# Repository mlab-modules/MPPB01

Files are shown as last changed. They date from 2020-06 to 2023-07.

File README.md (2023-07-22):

# MPPB01A -  Mechanical Parallella peripheral board

Elecromechanical interface to [Parallella board](https://parallella.org/). The module is especially useful for connection of [multi-channel](https://github.com/mlab-modules/ADCoctoSPI01) or [high-speed ADCs](https://www.mlab.cz/module/ADCdual01A). 

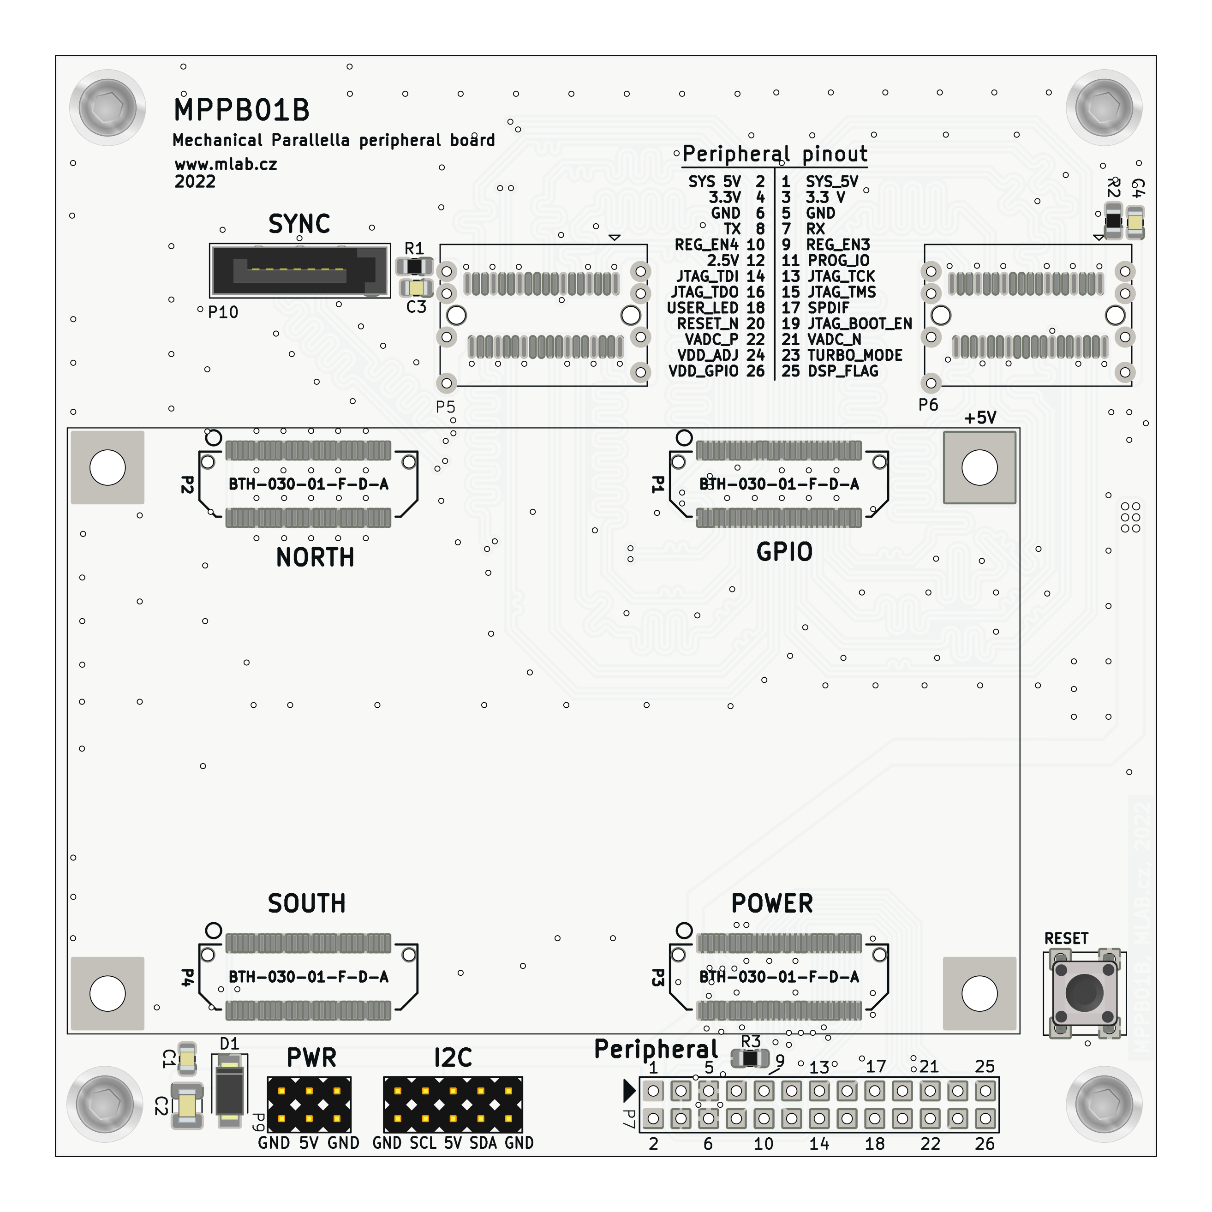
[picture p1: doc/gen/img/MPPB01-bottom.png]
MPPB01B

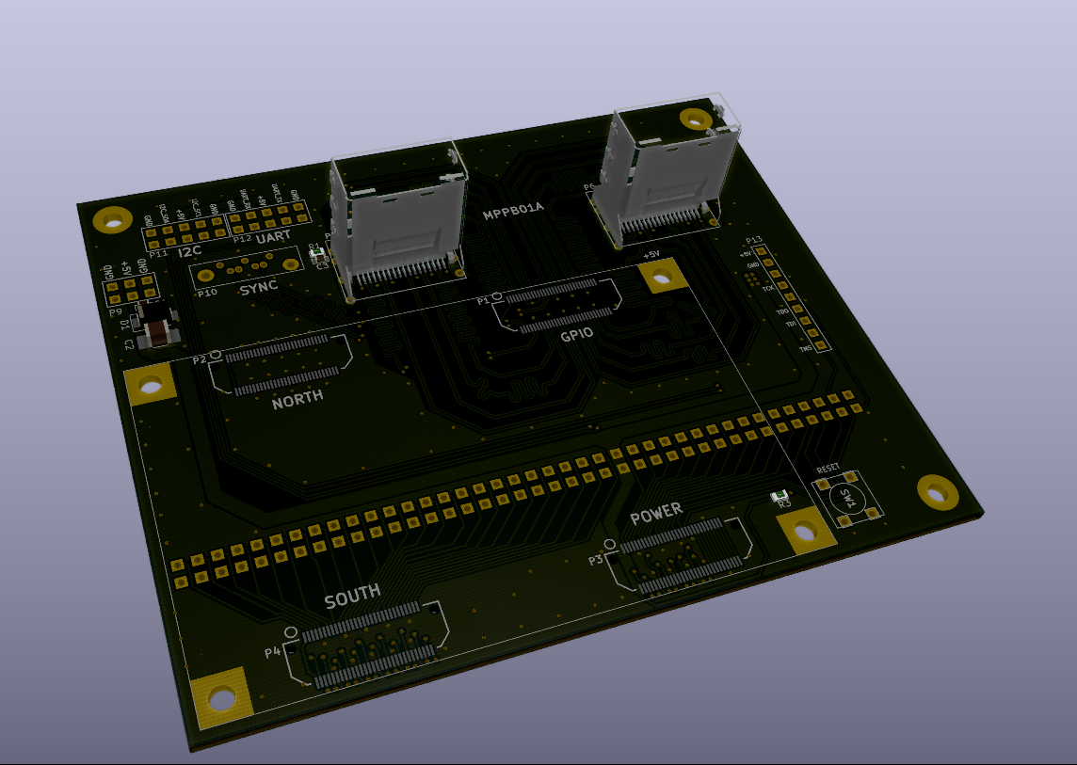
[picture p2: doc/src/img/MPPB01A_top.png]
MPPB01A Mechanical Parallella peripheral board


## Parameters

| Parameter | Value | Description |
|---|---|---|
| LVDS connector | 2x miniSAS |  |
| Service interface | Pin-header |  |
| Operating and storage temperature | -20 - +40°C |  |
| Operational input voltage | 4.9 - 5.2V |  |
| I²C interface levels | 5V |  |
| UART interface levels | 3.3V |  |

## Usage examples 

Lightning mapping devices
  * [VLF Radio Storm Monitoring Station ](https://github.com/UniversalScientificTechnologies/RSMS02)
  * [UHF Radio Storm Monitoring Station ](https://github.com/UniversalScientificTechnologies/RSMS01)

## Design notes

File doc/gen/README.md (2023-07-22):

# PCB

Board size: 101.09x101.09 mm (3.98x3.98 inches)

- This is the size of the rectangle that contains the board
- Thickness: 1.6 mm (63 mils)
- Material: FR4
- Finish: None
- Layers: 2
- Copper thickness: 35 µm

Solder mask: TOP / BOTTOM

- Color: Green

Silk screen: TOP / BOTTOM

- Color: White

Stackup:

| Name | Type | Color | Thickness | Material | Epsilon_r | Loss tangent |
|---|---|---|---|---|---|---|
| F.SilkS | Top Silk Screen | | | | | |
| F.Paste | Top Solder Paste | | | | | |
| F.Mask | Top Solder Mask | | 10 | | | |
| F.Cu | copper | | 35 | | | |
| dielectric 1 | core | | 1510 | FR4 | 4.5 | 0.020 |
| B.Cu | copper | | 35 | | | |
| B.Mask | Bottom Solder Mask | | 10 | | | |
| B.Paste | Bottom Solder Paste  | | | | | |
| B.SilkS | Bottom Silk Screen | | | | | |

# Important sizes

Clearance: 0.18 mm (7 mils)

Track width: 0.2 mm (8 mils)

- By design rules: 0.15 mm (6 mils)

Drill: 0.5 mm (20 mils)

- Vias: 0.5 mm (20 mils) [Design: 0.4 mm (16 mils)]
- Pads: 0.85 mm (33 mils)
- The above values are real drill sizes, they add 0.1 mm (4 mils) to plated holes (PTH)

Via: 0.75/0.4 mm (30/16 mils)

- By design rules: 0.6/0.3 mm (24/12 mils)
- Micro via: yes [0.5/0.2 mm (20/8 mils)]
- Buried/blind via: yes
- Total: 249 (thru: 249 buried/blind: 0 micro: 0)

Outer Annular Ring: 0.13 mm (5 mils)

- By design rules: 0.13 mm (5 mils)

Eurocircuits class: 6B
- Using min drill 0.5 mm for an OAR of 0.13 mm

# General stats

Components count: (SMD/THT)

- Top: 0/5 (THT)
- Bottom: 14/8 (SMD + THT)

Defined tracks:

- 0.25 mm (10 mils)

Used tracks:

- 0.2 mm (8 mils) (22) defined: no
- 0.25 mm (10 mils) (221) defined: yes
- 0.28 mm (11 mils) (5606) defined: no
- 0.3 mm (12 mils) (49) defined: no
- 0.5 mm (20 mils) (2) defined: no
- 1.5 mm (59 mils) (10) defined: no

Defined vias:

- 0.75/0.4 mm (30/16 mils)

Used vias:

- 0.75/0.4 mm (30/16 mils) (Count: 243, Aspect: 2.1 A) defined: yes
- 1.0/0.6 mm (39/24 mils) (Count: 6, Aspect: 1.6 A) defined: no

Holes (excluding vias):

- 0.74 mm (29 mils) (7)
- 0.8 mm (31 mils) (16)
- 0.89 mm (35 mils) (42)
- 1.0 mm (39 mils) (4)
- 1.02 mm (40 mils) (8)
- 1.35 mm (53 mils) (2)
- 1.55 mm (61 mils) (4)
- 3.0 mm (118 mils) (4)
- 3.18 mm (125 mils) (4)

Oval holes:

Drill tools (including vias and computing adjusts and rounding):

- 0.5 mm (20 mils) (243)
- 0.7 mm (28 mils) (6)
- 0.85 mm (33 mils) (7)
- 0.9 mm (35 mils) (16)
- 1.0 mm (39 mils) (50)
- 1.1 mm (43 mils) (4)
- 1.45 mm (57 mils) (2)
- 1.55 mm (61 mils) (4)
- 3.1 mm (122 mils) (4)
- 3.3 mm (130 mils) (4)

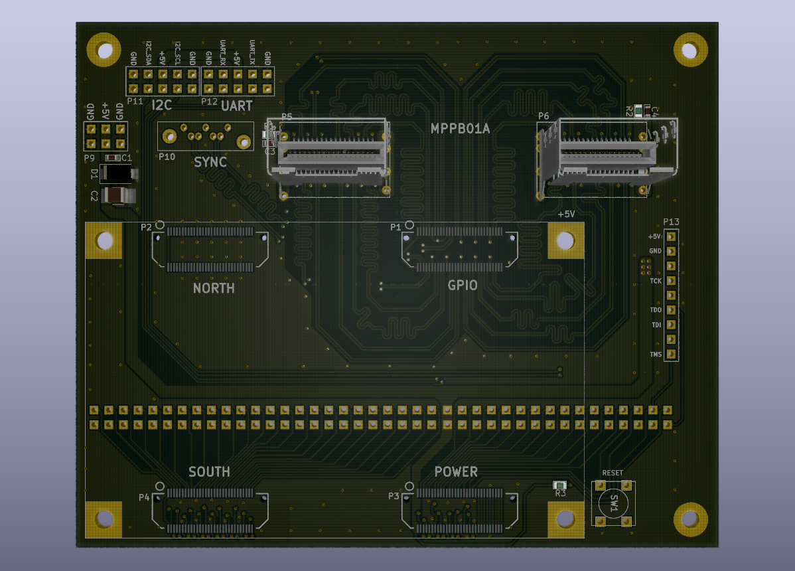
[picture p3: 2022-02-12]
doc/src/img/MPPB01A_PCB_top.png

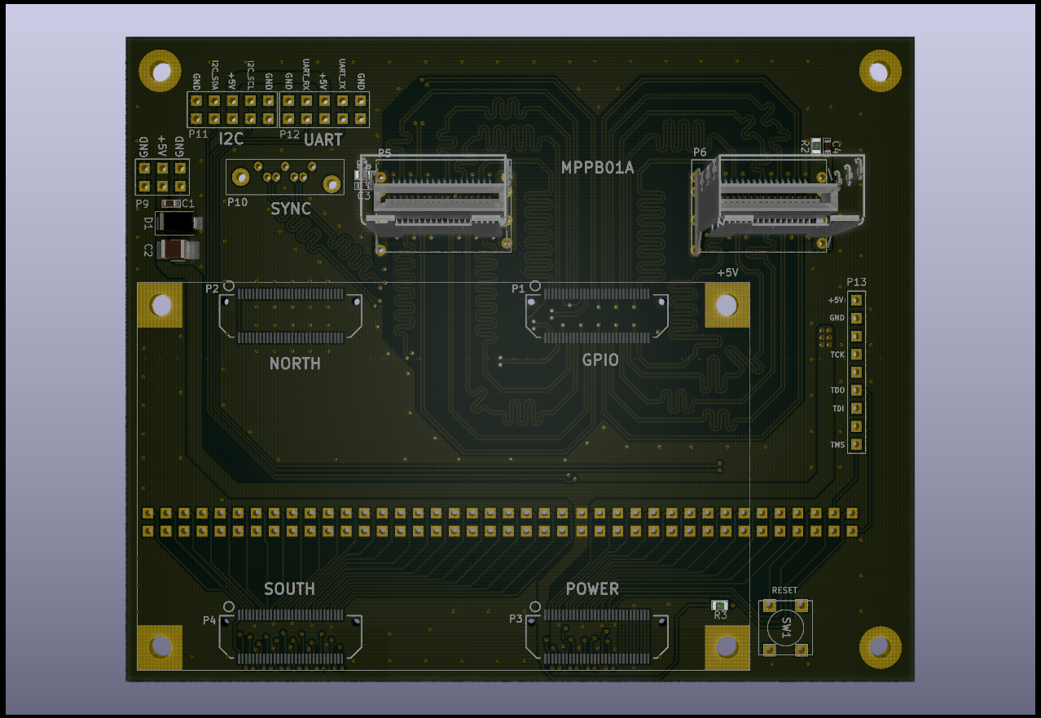
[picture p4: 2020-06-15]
doc/src/img/QFMIX01C_bottom.png

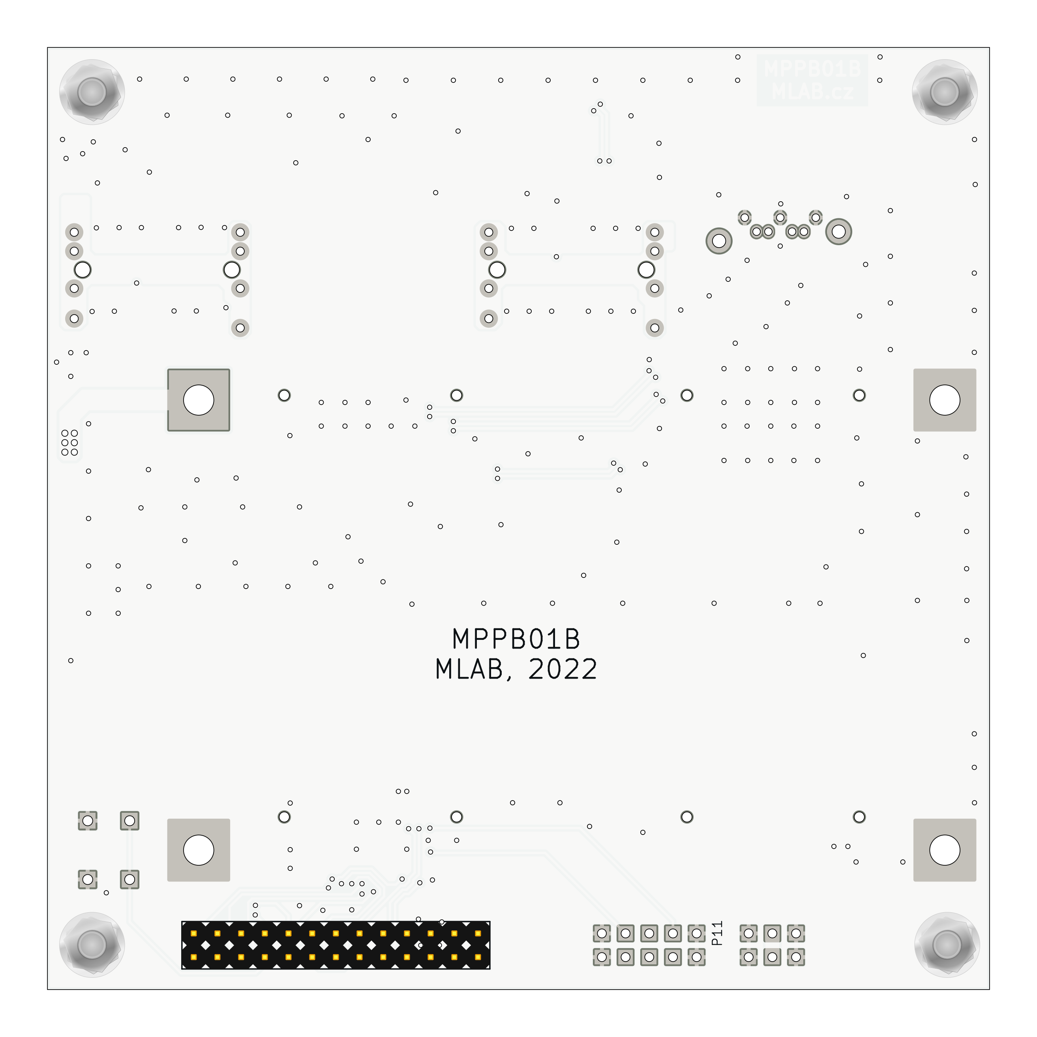
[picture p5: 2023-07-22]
doc/gen/img/MPPB01-top.png

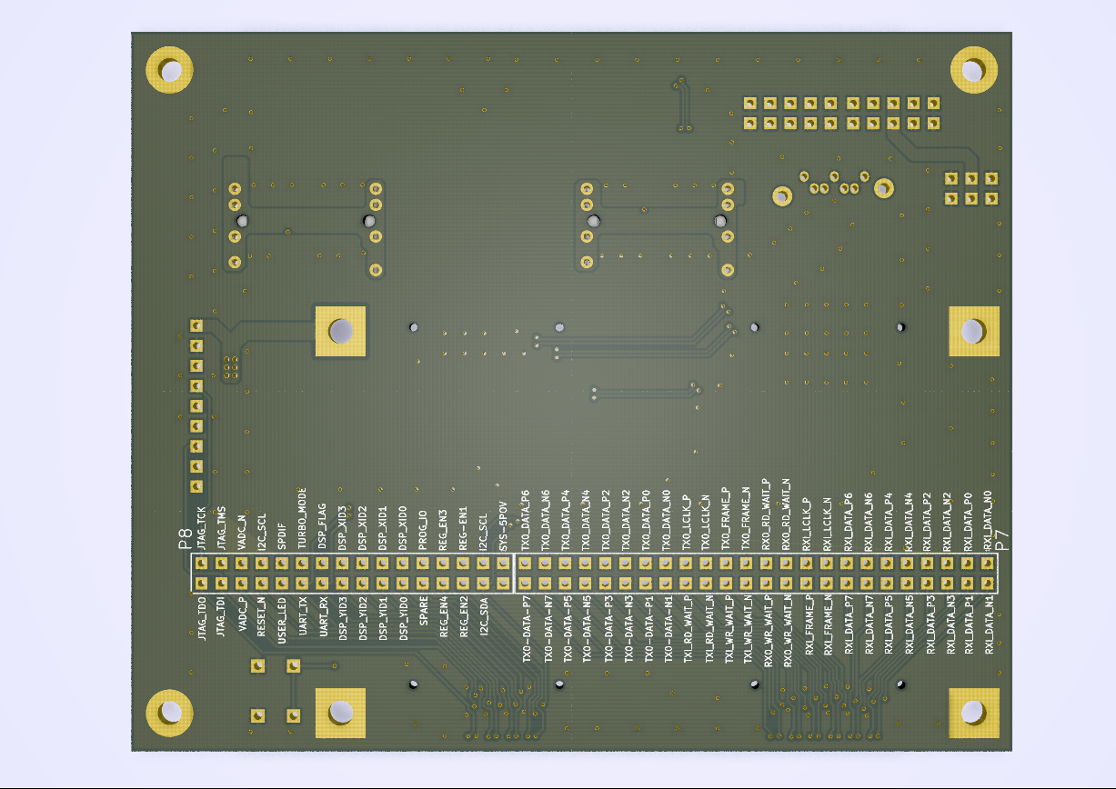
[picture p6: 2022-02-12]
doc/src/img/MPPB01A_PCB.png

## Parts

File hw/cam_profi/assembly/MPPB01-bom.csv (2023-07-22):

Component | Description | Part | References | Value | Footprint | Quantity Per PCB | Datasheet | ust_id | mfrpn | manufacturer
1 |  | C_Small-device | C1C3C4 | 100nF/16V | C_0805_2012Metric | 3 |  | 5c70984712875079b91f8b4c
2 |  | C_Small-device | C2 | 100uF/6V3 | C_1210_3225Metric | 1 |  | 5c70984712875079b91f8b80
3 |  | D_Small-device | D1 | M4 | D_SMA | 1 |  | 5c70984512875079b91f88ac
4 |  | MTG_PTH_125_SQ | MH1MH2MH3MH4 | MTG\PTH\125\SQ | MTG_PTH_125_SQ | 4
5 |  | CONN_SAMTEC_BTH_030 | P1P2P3P4 | BTH-030-01-F-D-A | SAMTEC-BTH-030-01-X-D-A | 4 | https://cz.mouser.com/datasheet/2/527/bth-2498158.pdf | 628e4f00243ef5997b12f43c | BTH-030-01-F-D-A | Samtec
6 | 2x03 2.54 mm pitch header, 2 pins next to each other are connected | HEADER_2x03_PARALLEL | P9 | HEADER_2x03_PARALLEL | Straight_2x03 | 1
7 | 2x05 2.54 mm pitch header, 2 pins next to each other are connected | HEADER_2x05_PARALLEL | P11 | HEADER_2x05_PARALLEL | Straight_2x05 | 1
8 | 2x13 2.54 mm pitch header | HEADER_2x13 | P7 | HEADER_2x13 | Straight_2x13 | 1
9 |  | SAS_mini_1888174-MLAB_CONNECTORS | P5P6 | SAS_mini_1888174-6 | SAS-mini_TEConnectivity_1888174_Vertical | 2 |  | 624ede60592c2d62176d5a96
10 |  | SATA7-67491-1030 | P10 | SATA7-67491-1030 | SATA-7_THT_VERT_2 | 1 |  | 5c70984712875079b91f8a7b
11 |  | R-device | R1R2 | 100 | R_0805_2012Metric_Pad1.20x1.40mm_HandSolder | 2 |  | 5c70984512875079b91f8977
12 |  | R-device | R3 | 10k | R_0805_2012Metric_Pad1.20x1.40mm_HandSolder | 1 |  | 5c70984612875079b91f899f
13 | Push button switch, generic, two pins | SW_Push | SW1 | Prepinac | SW_PUSH_SMALL | 1 | ~ | 5c70984712875079b91f8ad1

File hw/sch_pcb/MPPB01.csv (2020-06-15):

Id | Designator | Package | Quantity | Designation | Supplier and ref
1 | P1,P2,P3,P4 | CONN_SAMTEC_BTH_60 | 4 | BTH-030-01-F-D-A
2 | P5,P6 | SAS_mini_1888174 | 2 | SAS_mini_1888174
3 | MH1,MH2,MH3,MH4 | MTG_PTH_125_SQ | 4 | MTG\PTH\125\SQ
4 | P8 | Straight_2x03 | 1 | HEADER_2x03_PARALLEL
5 | P9 | SATA-7_THT_VERT_2 | 1 | SATA7-67491-1030
6 | MH5,MH6,MH7,MH8 | MountingHole_3mm | 4 | HOLE
7 | C1 | C_0603 | 1 | 100nF/16V
8 | C2 | C_1210_HandSoldering | 1 | 100uF/10V
9 | P7 | Straight_2x05 | 1 | HEADER_2x05_PARALLEL
10 | D1 | D_SMA | 1 | M4

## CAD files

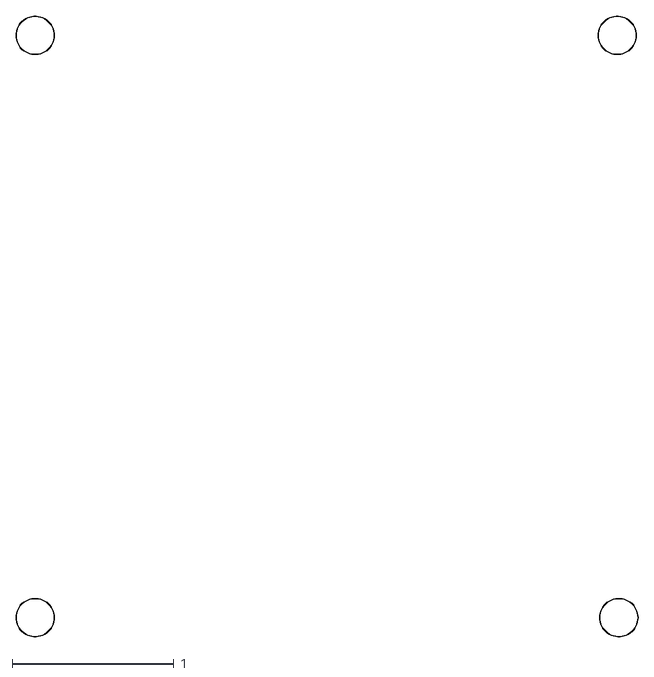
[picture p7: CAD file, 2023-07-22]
doc/gen/dxf/MPPB01-B_Adhesive.dxf
3.85 x 3.84

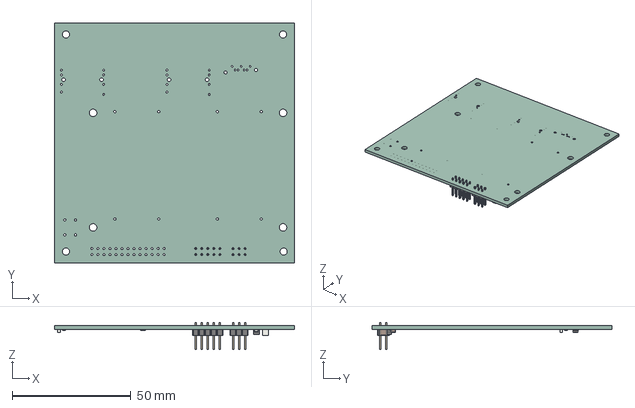
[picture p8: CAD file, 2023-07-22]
doc/gen/MPPB01.step
101.1 x 101.1 x 11.5 mm
tmpv6ou7w8n PCB

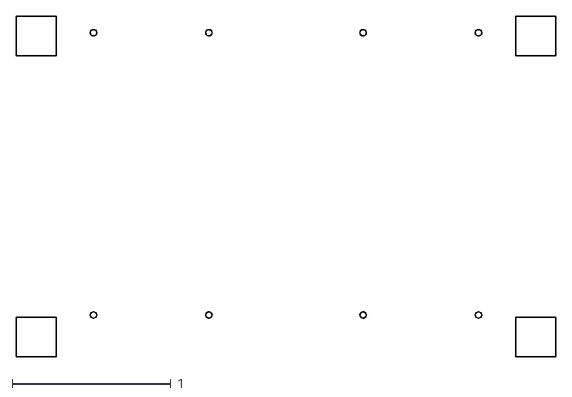
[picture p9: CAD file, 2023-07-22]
doc/gen/dxf/MPPB01-User_Drawings.dxf
3.40 x 2.15

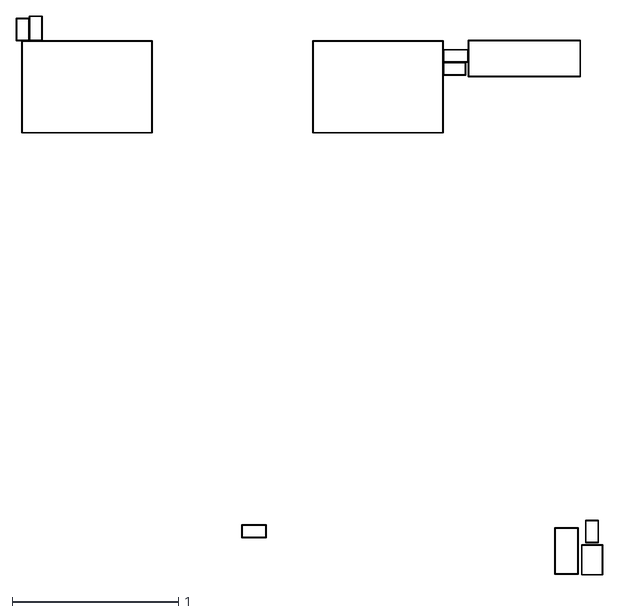
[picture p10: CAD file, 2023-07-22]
doc/gen/dxf/MPPB01-B_Courtyard.dxf
3.53 x 3.36

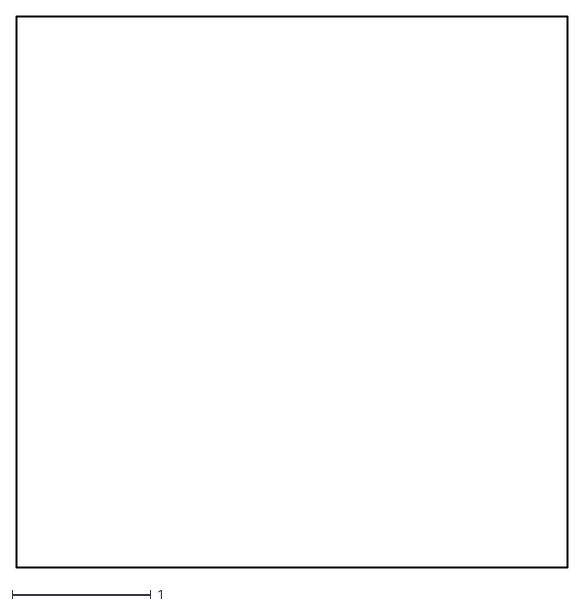
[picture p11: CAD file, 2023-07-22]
doc/gen/dxf/MPPB01-Edge_Cuts.dxf
3.98 x 3.98

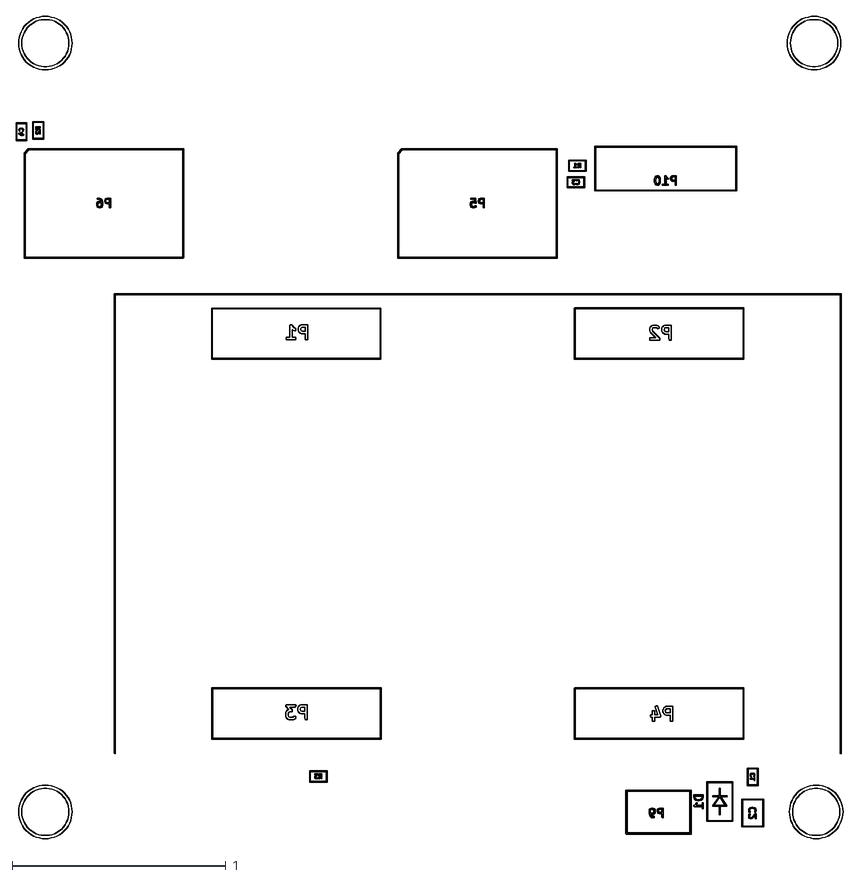
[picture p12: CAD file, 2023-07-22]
doc/gen/dxf/MPPB01-B_Fab.dxf
3.87 x 3.85

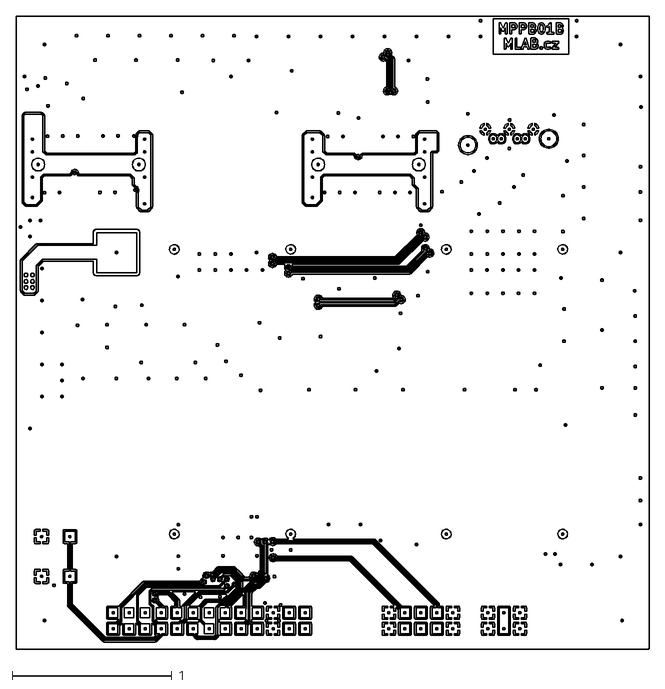
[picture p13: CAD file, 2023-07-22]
doc/gen/dxf/MPPB01-F_Cu.dxf
3.96 x 3.96

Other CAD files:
doc/gen/dxf/MPPB01-User_Eco2.dxf
doc/gen/dxf/MPPB01-F_Fab.dxf
doc/gen/dxf/MPPB01-User_Eco1.dxf
doc/gen/dxf/MPPB01-F_Courtyard.dxf
doc/gen/dxf/MPPB01-User_Comments.dxf
doc/gen/dxf/MPPB01-Margin.dxf
doc/gen/dxf/MPPB01-B_Mask.dxf
doc/gen/dxf/MPPB01-B_Paste.dxf
doc/gen/dxf/MPPB01-B_Silkscreen.dxf
doc/gen/dxf/MPPB01-F_Mask.dxf
doc/gen/dxf/MPPB01-F_Paste.dxf
doc/gen/dxf/MPPB01-F_Silkscreen.dxf

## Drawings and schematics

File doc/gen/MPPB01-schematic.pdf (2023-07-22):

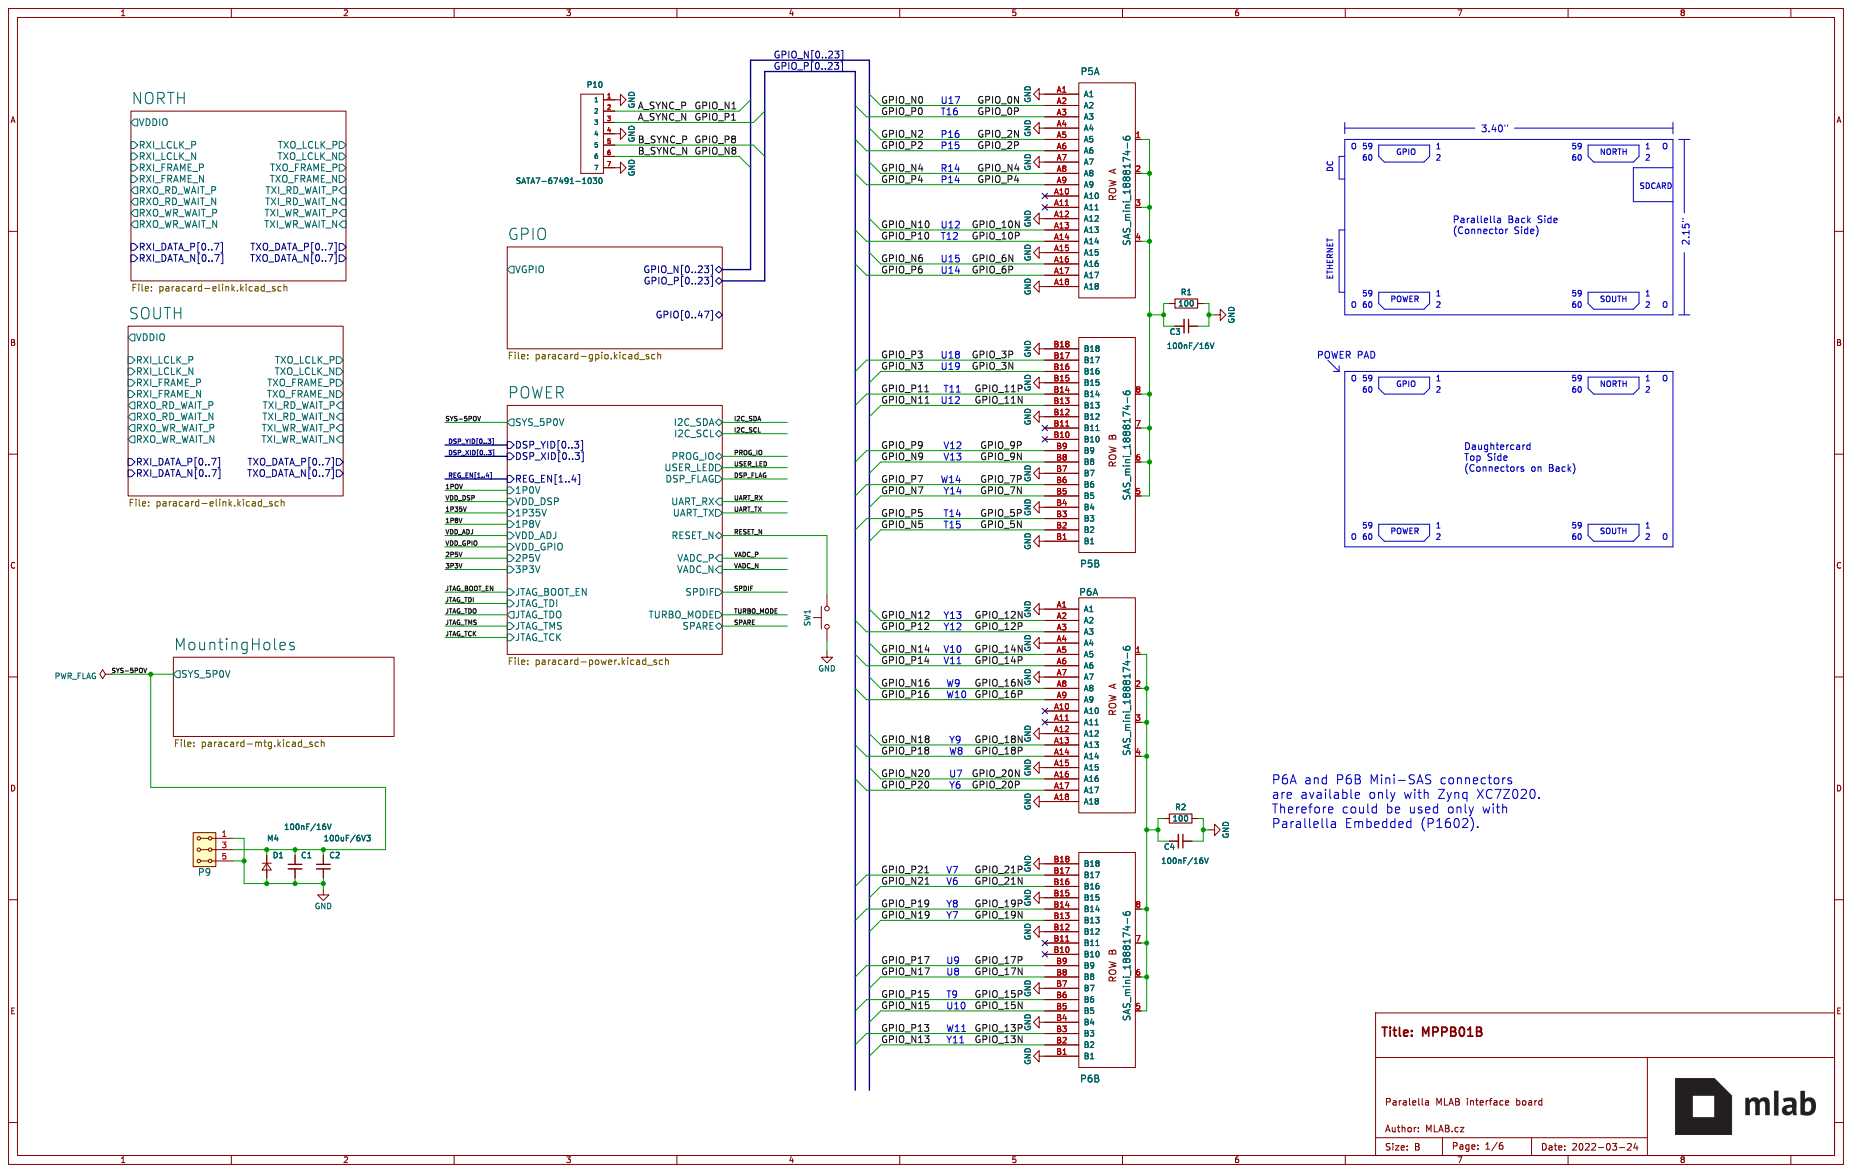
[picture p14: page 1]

100 GND GND GND GND GND GND 135 P9

Therefore could be used only with

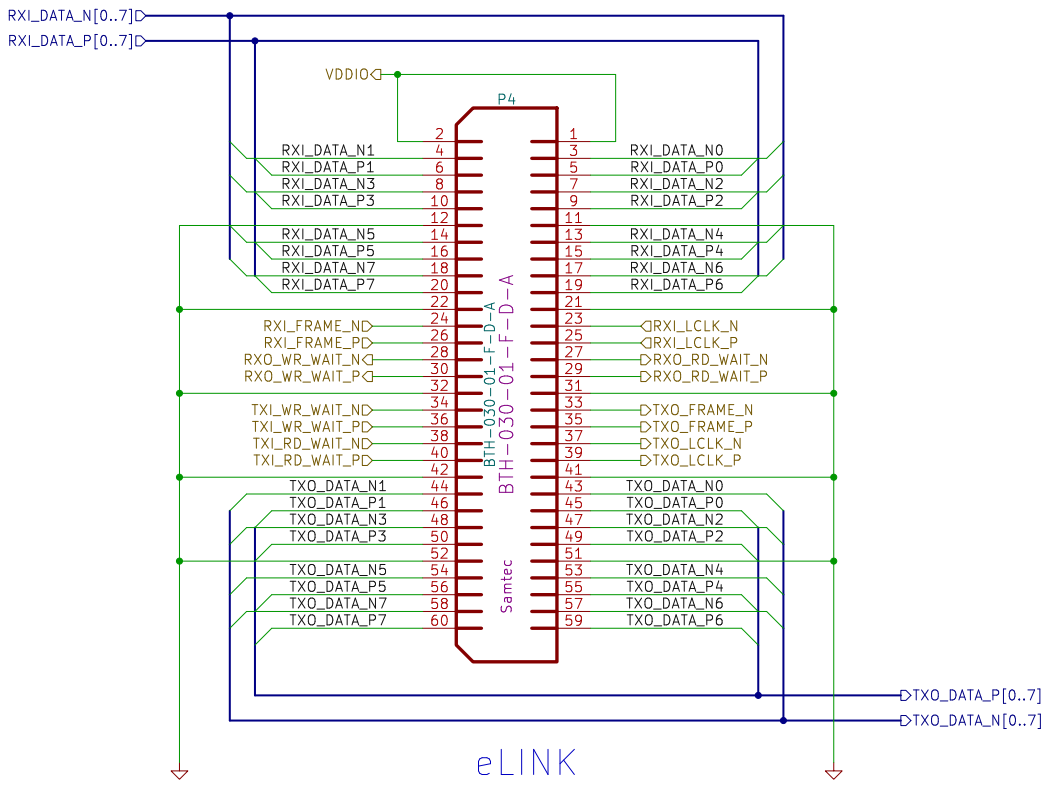
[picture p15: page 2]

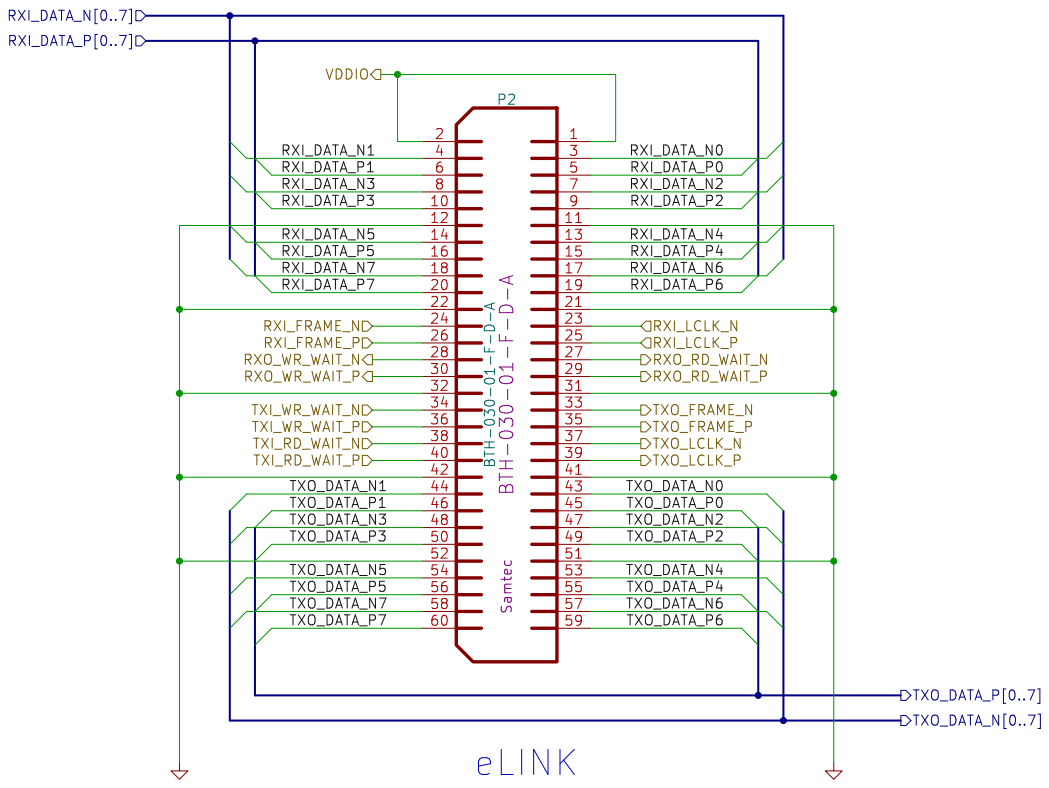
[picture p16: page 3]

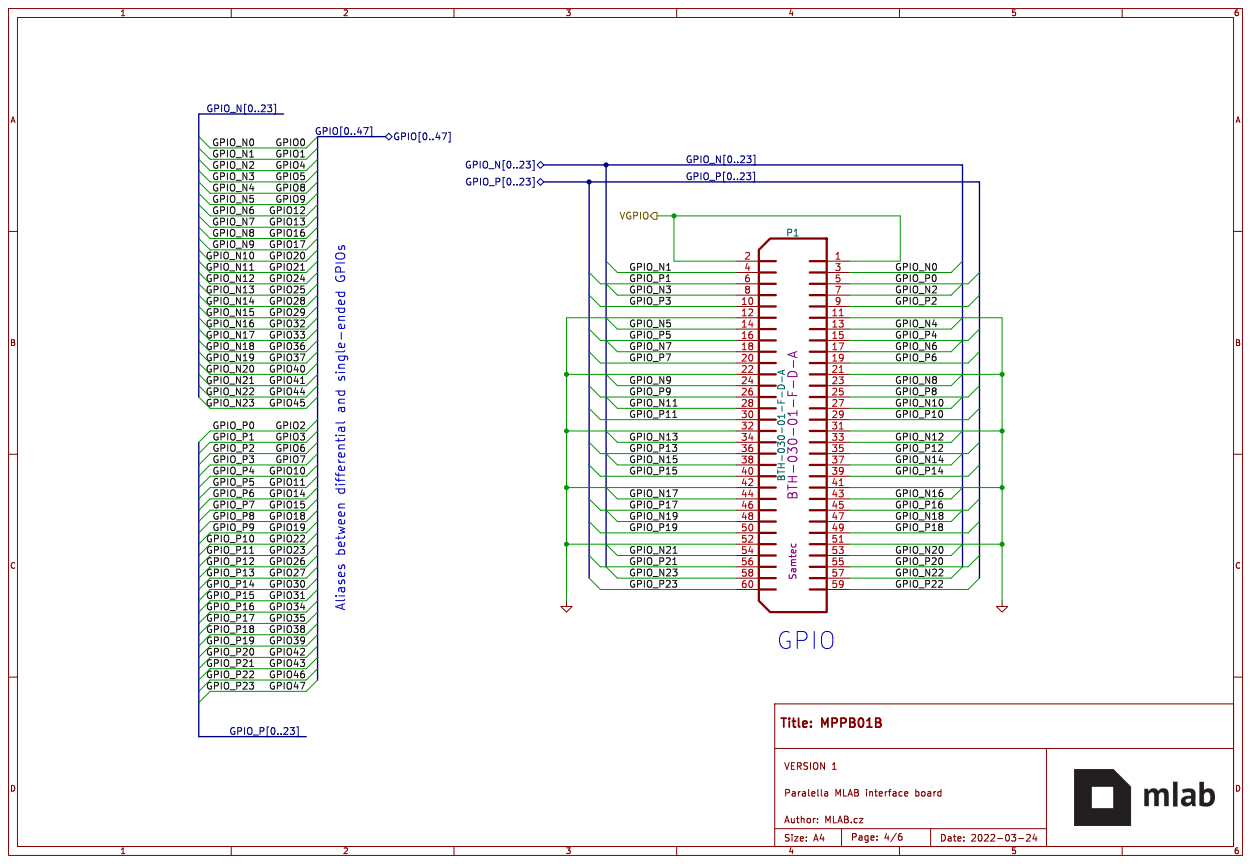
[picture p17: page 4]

GPIO_P13 Aliases between differential and single-ended GPIOs

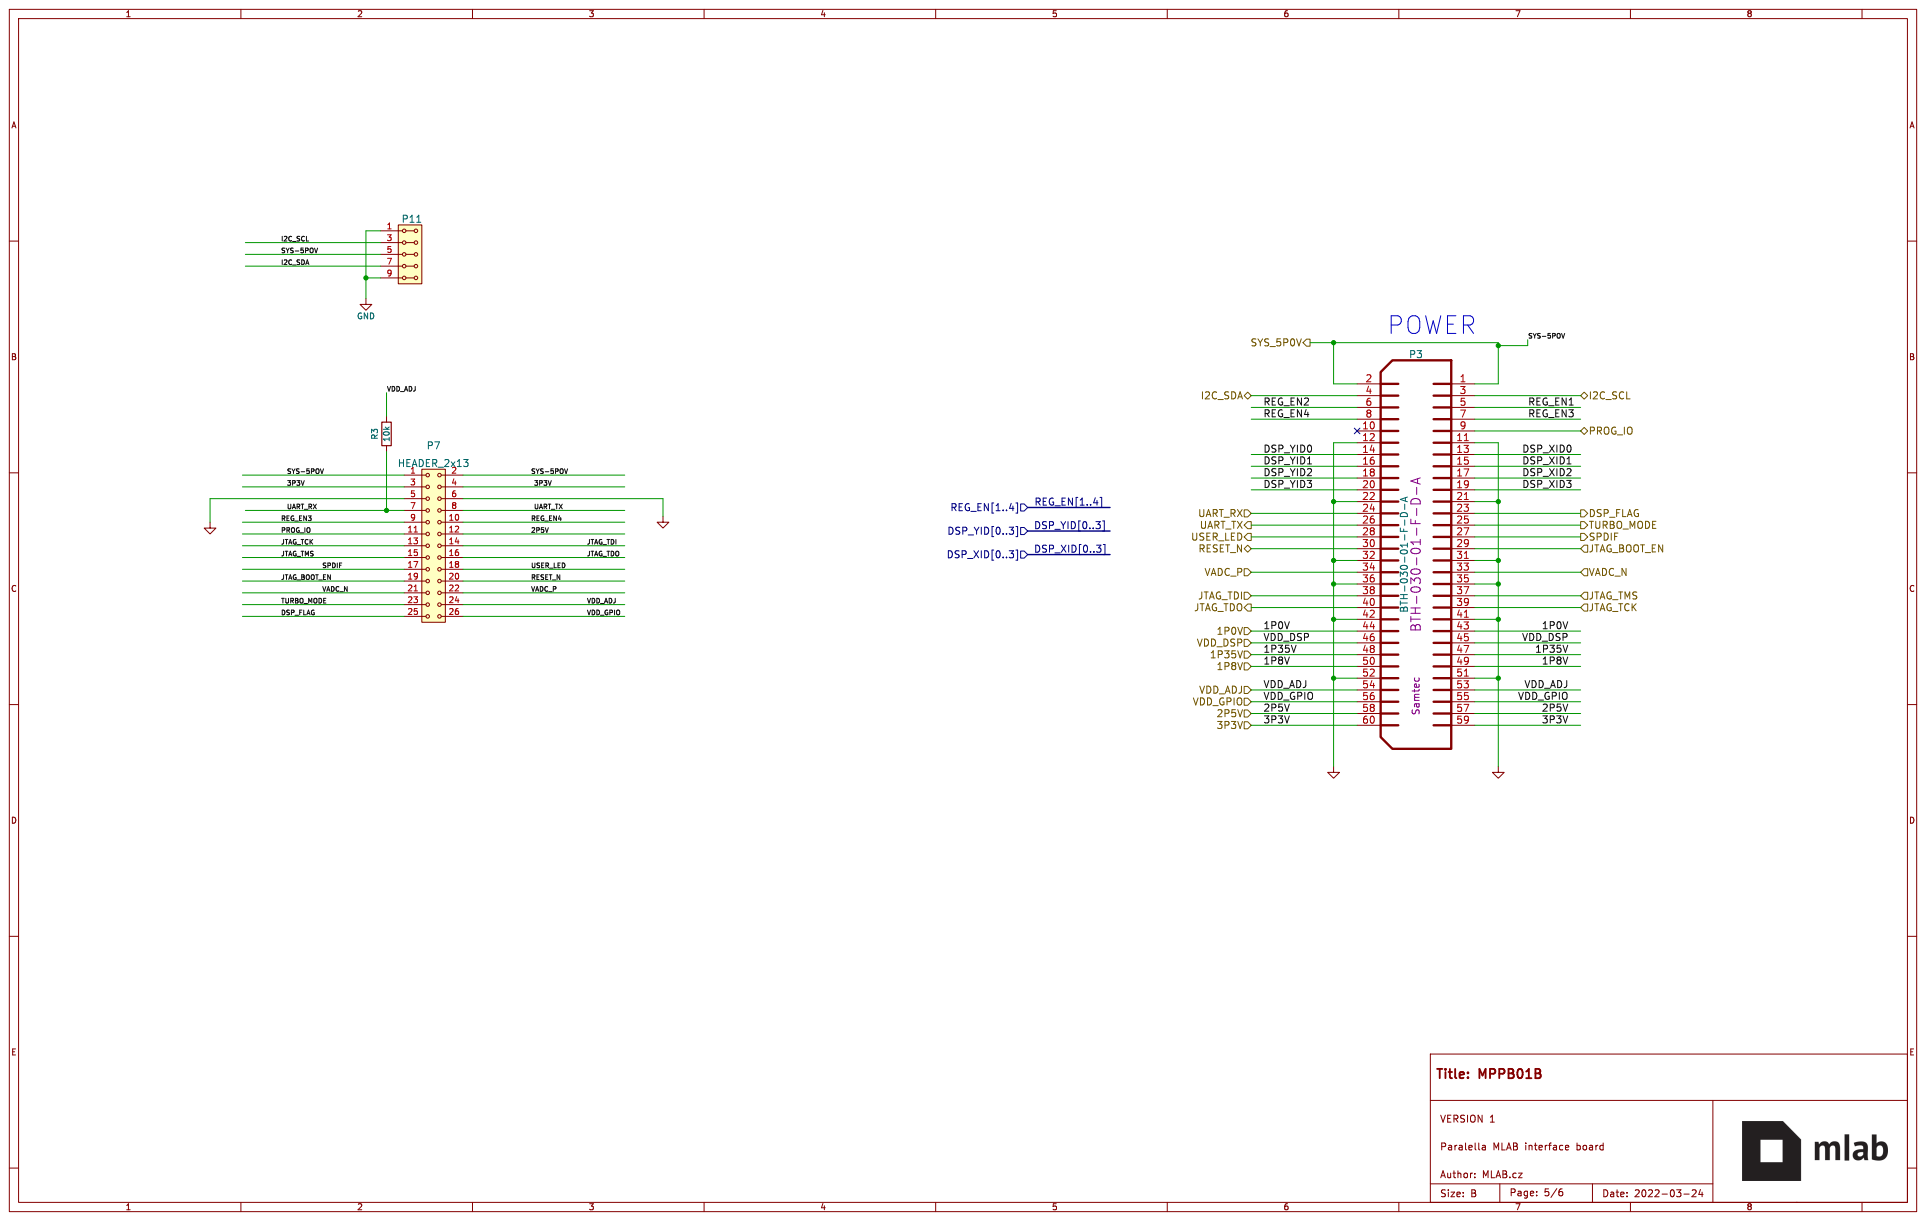
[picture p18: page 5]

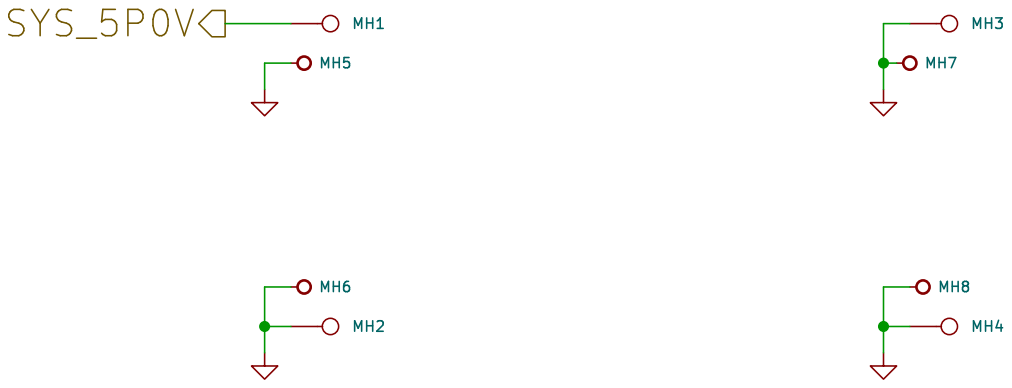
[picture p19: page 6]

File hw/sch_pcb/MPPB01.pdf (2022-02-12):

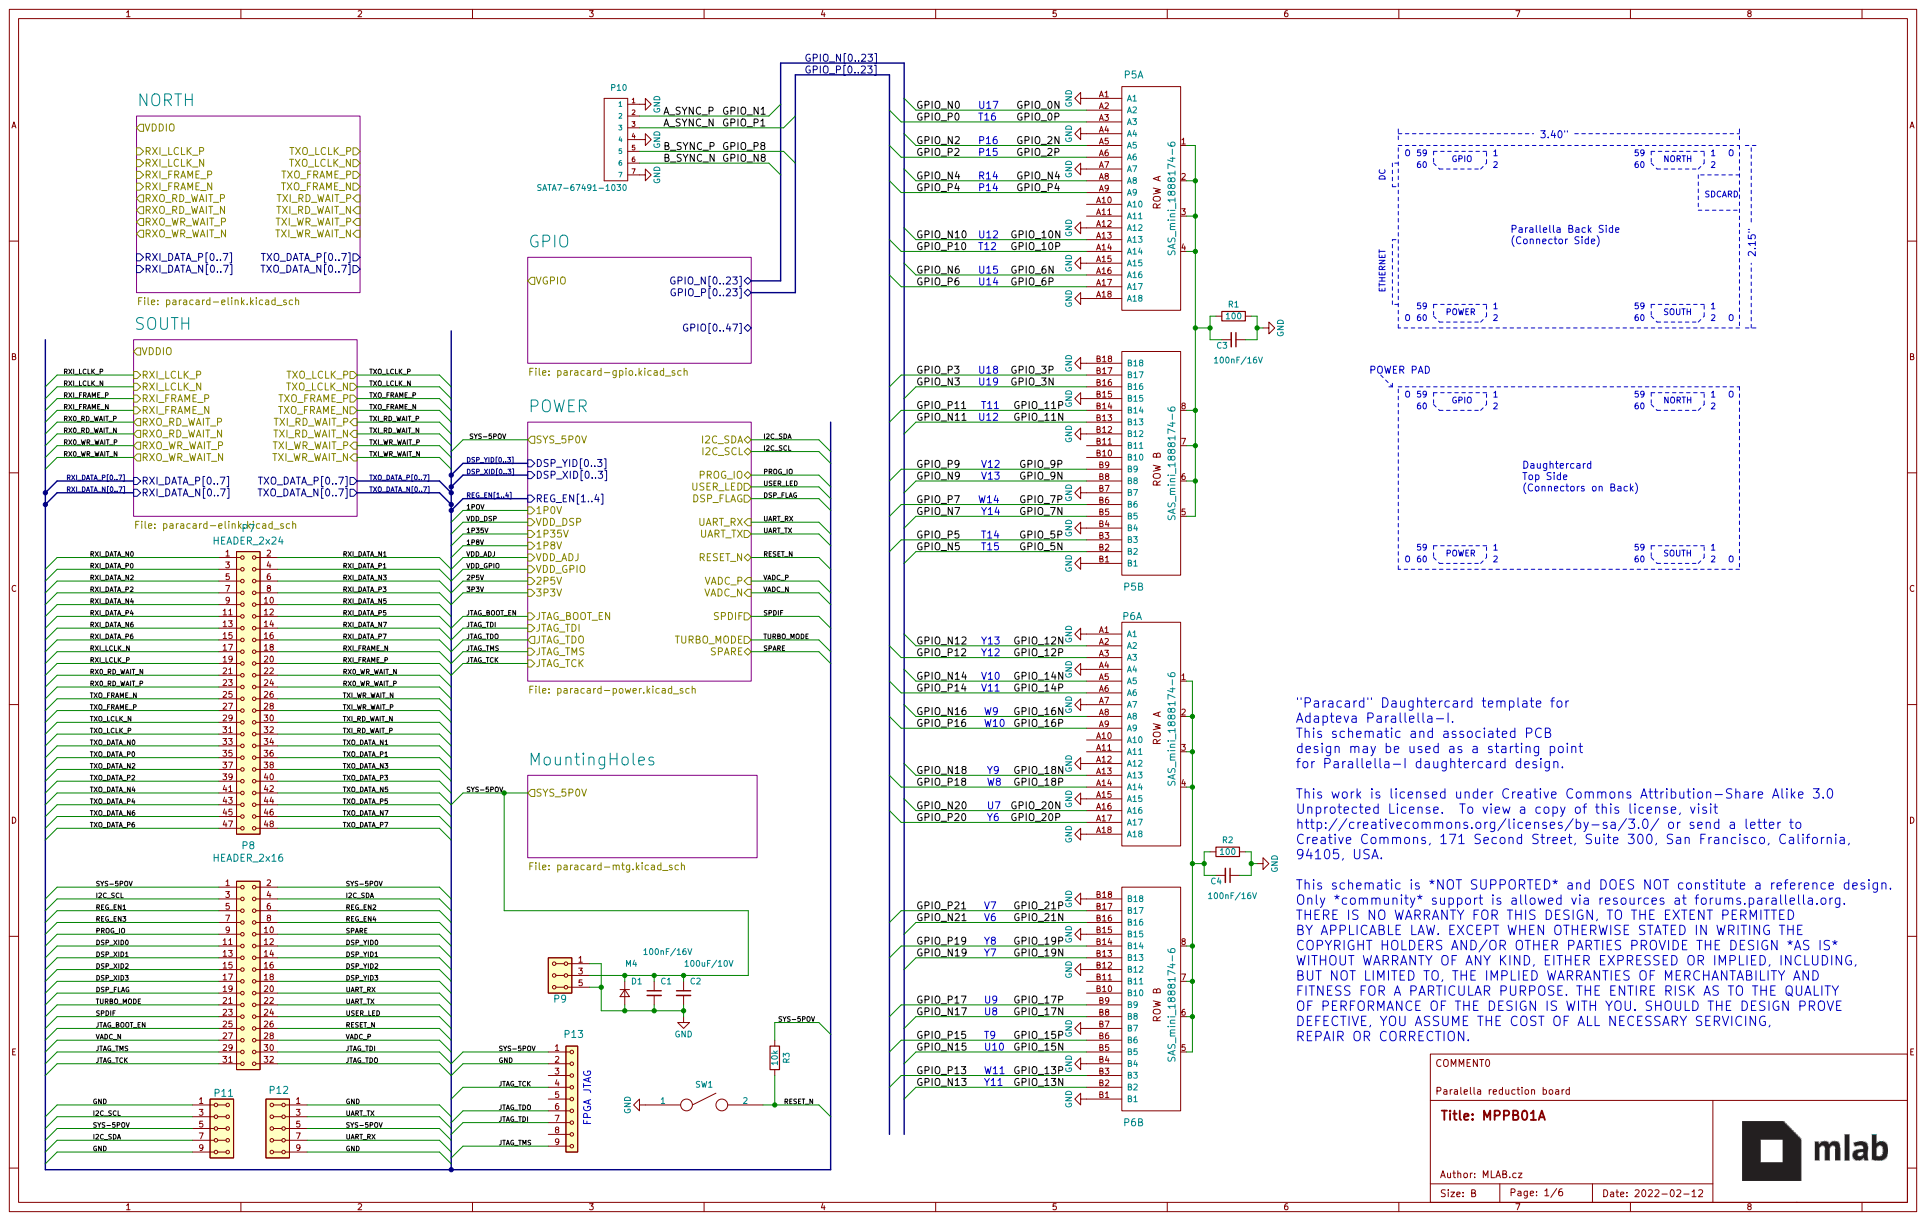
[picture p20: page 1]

(Connectors on Back) GPIO

"Paracard" Daughtercard template for
Adapteva Parallella-I.
This schematic and associated PCB
design may be used as a starting point
for Parallella-I daughtercard design.

This work is licensed under Creative Commons Attribution-Share Alike 3.0
Unprotected License. To view a copy of this license, visit
http://creativecommons.org/licenses/by-sa/3.0/ or send a letter to
Creative Commons, 171 Second Street, Suite 300, San Francisco, California,
94105, USA.

This schematic is *NOT SUPPORTED* and DOES NOT constitute a reference design.
Only *community* support is allowed via resources at forums.parallella.org.
THERE IS NO WARRANTY FOR THIS DESIGN, TO THE EXTENT PERMITTED
BY APPLICABLE LAW. EXCEPT WHEN OTHERWISE STATED IN WRITING THE
COPYRIGHT HOLDERS AND/OR OTHER PARTIES PROVIDE THE DESIGN *AS IS*
WITHOUT WARRANTY OF ANY KIND, EITHER EXPRESSED OR IMPLIED, INCLUDING,
BUT NOT LIMITED TO, THE IMPLIED WARRANTIES OF MERCHANTABILITY AND
FITNESS FOR A PARTICULAR PURPOSE. THE ENTIRE RISK AS TO THE QUALITY
OF PERFORMANCE OF THE DESIGN IS WITH YOU. SHOULD THE DESIGN PROVE
DEFECTIVE, YOU ASSUME THE COST OF ALL NECESSARY SERVICING,
REPAIR OR CORRECTION.

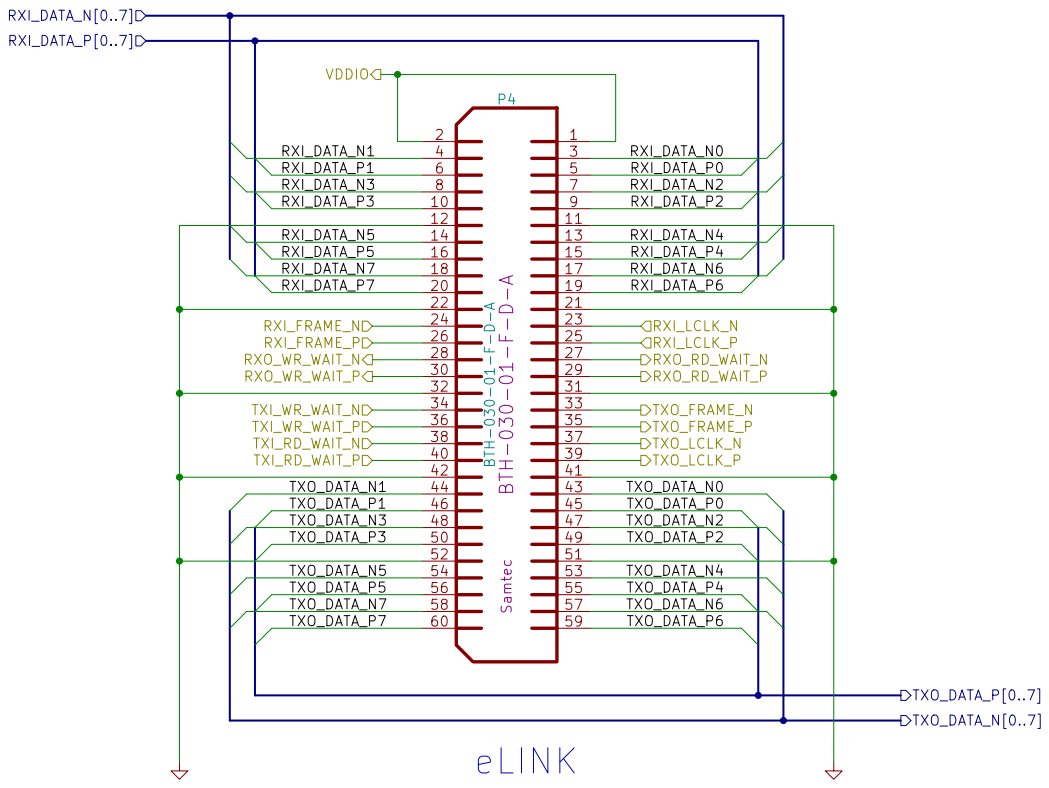
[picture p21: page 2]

RXI_DATA_N5
RXI_DATA_P5

COMMENT0 VERSION 1 Paralella reduction board

Title: MPPB01A

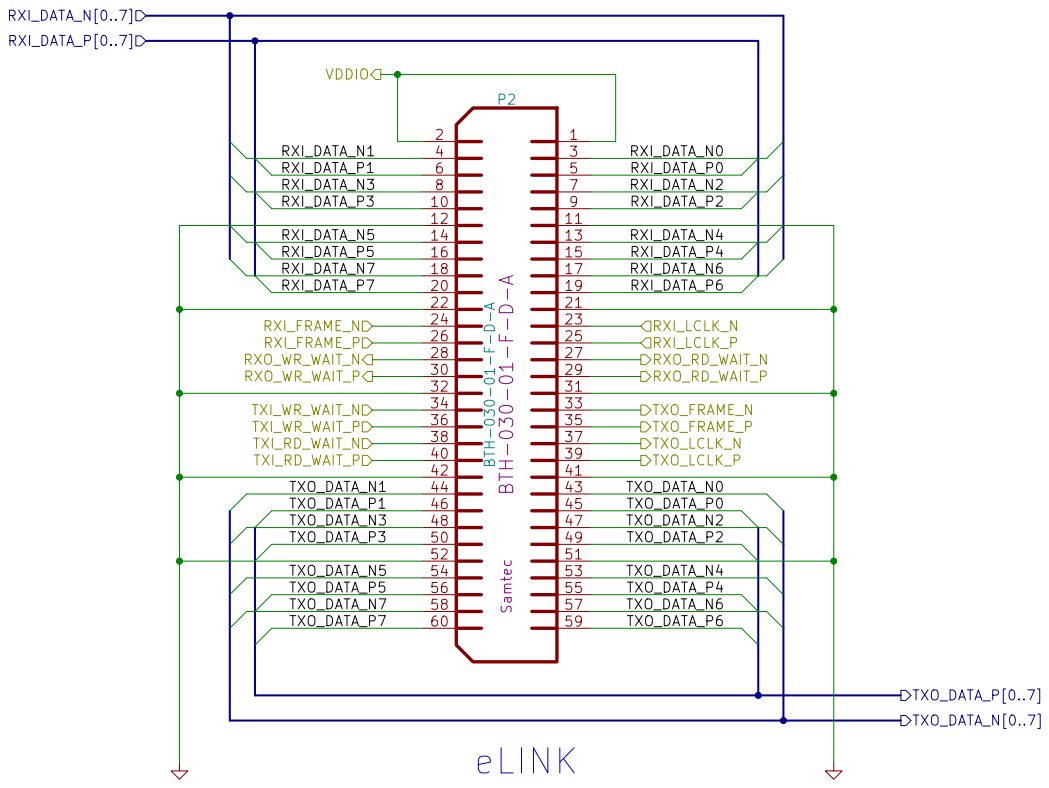
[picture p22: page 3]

RXI_DATA_N5
RXI_DATA_P5

COMMENT0 VERSION 1 Paralella reduction board

Title: MPPB01A

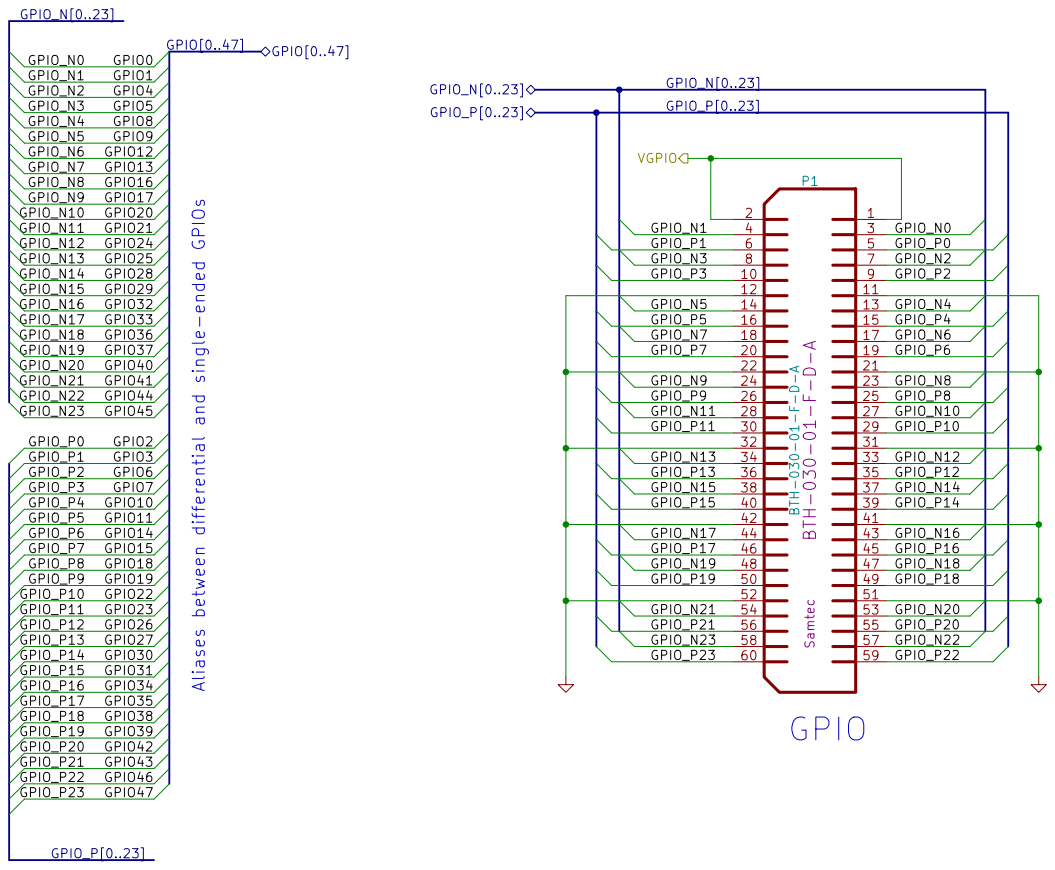
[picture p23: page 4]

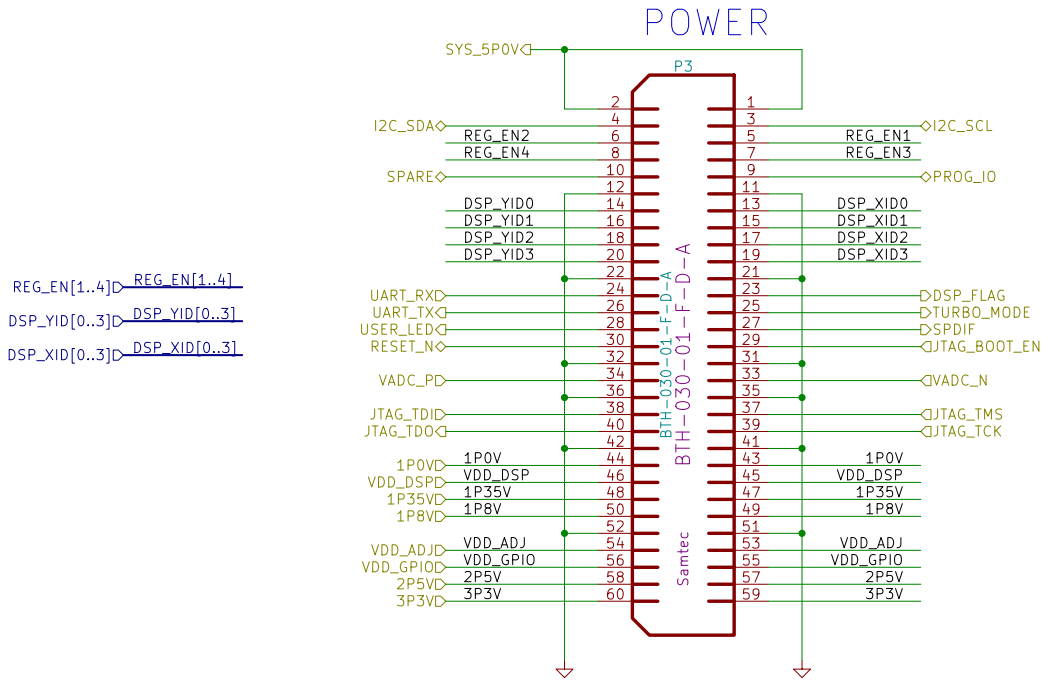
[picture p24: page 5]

COMMENT0 VERSION 1 Paralella reduction board

Title: MPPB01A

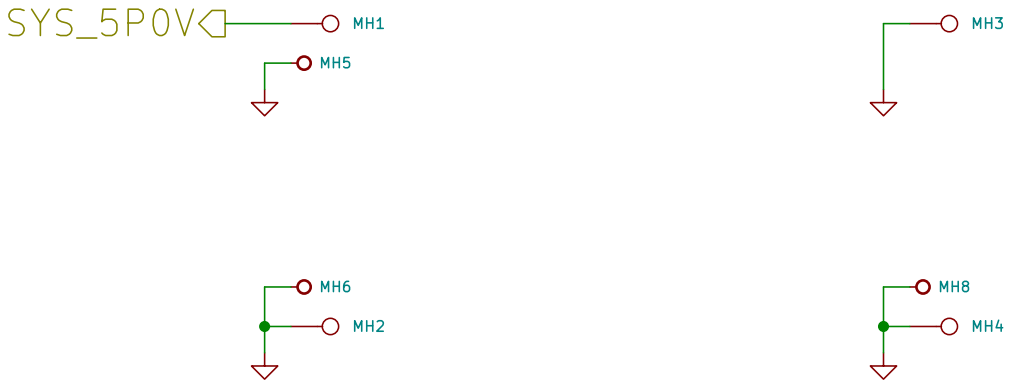
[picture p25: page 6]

COMMENT0 VERSION 1 Paralella reduction board

Title: MPPB01A



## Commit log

2020-06-15 Initial commit of design
    [DENGS_CON.sch, paracard-elink.sch, paracard-gpio.sch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]
2022-02-12 Update KiCAD project to version 6.0.1.
    [MPPB01A.csv, MPPB01A.kicad_pcb, MPPB01A.kicad_sch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]
2022-02-12 Update and improve documentation.
    [MPPB01A.kicad_sch, paracard-gpio.kicad_sch]
2022-03-24 Update schematics. Preparation to resolve #2.
    [MPPB01A.kicad_pcb, MPPB01A.kicad_sch, paracard-elink.kicad_sch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]
2022-03-24 Update footprints #2.
    [MPPB01A.kicad_pcb]
2022-03-24 Change footprints to standard KiCAD footprints.
    [MPPB01A.kicad_pcb, MPPB01A.kicad_sch, paracard-elink.kicad_sch]
2022-03-24 Removing redundant pull-up.
    [MPPB01A.kicad_sch]
2022-03-25 Adding pull-up resistor to resolve #1.
    Geometric preparation for #2.
    [MPPB01A.kicad_pcb, MPPB01A.kicad_sch, paracard-mtg.kicad_sch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]
2022-03-27 Update miniSAS connectors footprints. Resolved #3
    [MPPB01A.kicad_pcb, MPPB01A.kicad_sch]
2022-04-07 Edit bom
    [MPPB01A.kicad_pcb, MPPB01A.kicad_sch, paracard-elink.kicad_sch]
2022-04-07 Rename project
    [MPPB01B.csv, MPPB01B.kicad_pcb, MPPB01B.kicad_sch]
2022-04-07 Edit bom and footprint
    [MPPB01B.kicad_pcb, MPPB01B.kicad_sch]
2022-04-08 Improve connector pinout #2
    [DENGS_CON.sch, MPPB01B.kicad_pcb, MPPB01B.kicad_sch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]
2022-05-13 routing cest ke konektoru
    [MPPB01B.kicad_pcb, MPPB01B.kicad_sch, paracard-elink.kicad_sch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]
2022-05-14 presun hrebinku
    [MPPB01B.kicad_pcb]
2022-05-14 uprava pinoutu konektoru
    [MPPB01B.kicad_pcb, MPPB01B.kicad_sch, paracard-power.kicad_sch]
2022-05-14 Update actions products
    [MPPB01B-B_Adhesive.dxf, MPPB01B-B_Courtyard.dxf, MPPB01B-B_Fab.dxf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]
2022-05-15 Routovani cesticek, uprava pinoutu
    [MPPB01B.kicad_pcb, MPPB01B.kicad_sch, paracard-power.kicad_sch]
2022-05-15 uprava silkscreenu
    [MPPB01B.kicad_pcb]
2022-05-15 Minor improvements in silksceen layout.
    [MPPB01B.kicad_pcb]
2022-05-16 Uprava silksceenu, DRC
    [MPPB01B.kicad_pcb]
2022-05-16 pridani UST_ID
    [MPPB01B.kicad_sch, paracard-power.kicad_sch]
2022-05-21 Edit PCB
    [MPPB01B.kicad_pcb]
2022-05-25 Priprava pro osazeni
    [MPPB01B.kicad_pcb, MPPB01B.kicad_sch, paracard-elink.kicad_sch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]
2023-07-21 update assets, save as 7
    [MPPB01.csv, MPPB01.kicad_pcb, MPPB01.kicad_sch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]
